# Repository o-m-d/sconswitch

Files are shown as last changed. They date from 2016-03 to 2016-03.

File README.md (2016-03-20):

# Serial Controlled Switch

## Device description
Device have 32 high voltage open collector outputs, controlled by commands
via RS-232 port. Outputs can be in active or passive state and can drive
relays, solenoids, LEDs, opto triacs etc.
Active state - output transistor open, passive state - output transistor
closed.

Device can be used in power control, lighting or any other suitable
applications.

Device connects to controlled system via 40-wire ribbon cable and to
controlling host via DE9 connector.

Device IS NOT realtime and may not used in time-sensitive applications,
e.g. CNC.

Device built on microcontroller ATmega8515-16 in TQFP44 package and
drivers ULN2803A in SOIC-18 package.

In firmware part used [KonstantinChizhov/Mcucpp library] (https://github.com/KonstantinChizhov/Mcucpp)
and [Peter Fleury UART library] (http://homepage.hispeed.ch/peterfleury/avr-software.html).
Firmware compiled by avr-gcc-4.8, pcb designed in KiCAD-4.0.1.

## Supported commands
<pre>
a N|a   - Active output number N (or all)
p N|a   - Passive output number N (or all)
t N D   - Toggle output N for D (1-255) seconds, press s for stop during 
          countdown
n NAME  - Output name, set to NAME or unset if empty given
s       - Show output status
h or ?  - Show this help
</pre>

Output status saved automatically to EEPROM with Active or Passive commands
and restored when power-up.
Commands are not case sensitive. Command line are not editable.

Outputs have numbers from 0 to 31. Toggle means temporary inversion of
output state.

[Demo video](https://youtu.be/6nN7ayRqDR0)

## Electrical characteristics
<pre>
Supply voltage: 9-15V
Supply current: 25mA at 10V
Max voltage on closed output: 50V
Max current via one open output: 500mA
Max total current via all open outputs: 4A (125mA per output and 2x2A per
two ground wires in ribbon cable)
</pre>

Characteristics depend on applied components.

## RS-232 mode
9600 8N1

## Design Recommendations
* Use short as possible ribbon cable.
* Use only 40-wire ribbon cable, not 80-wire UDMA cable.
* ULN2803 have built-in surge protection diodes for inductive load, but
better use discrete diodes, placed as close as possible to coil.

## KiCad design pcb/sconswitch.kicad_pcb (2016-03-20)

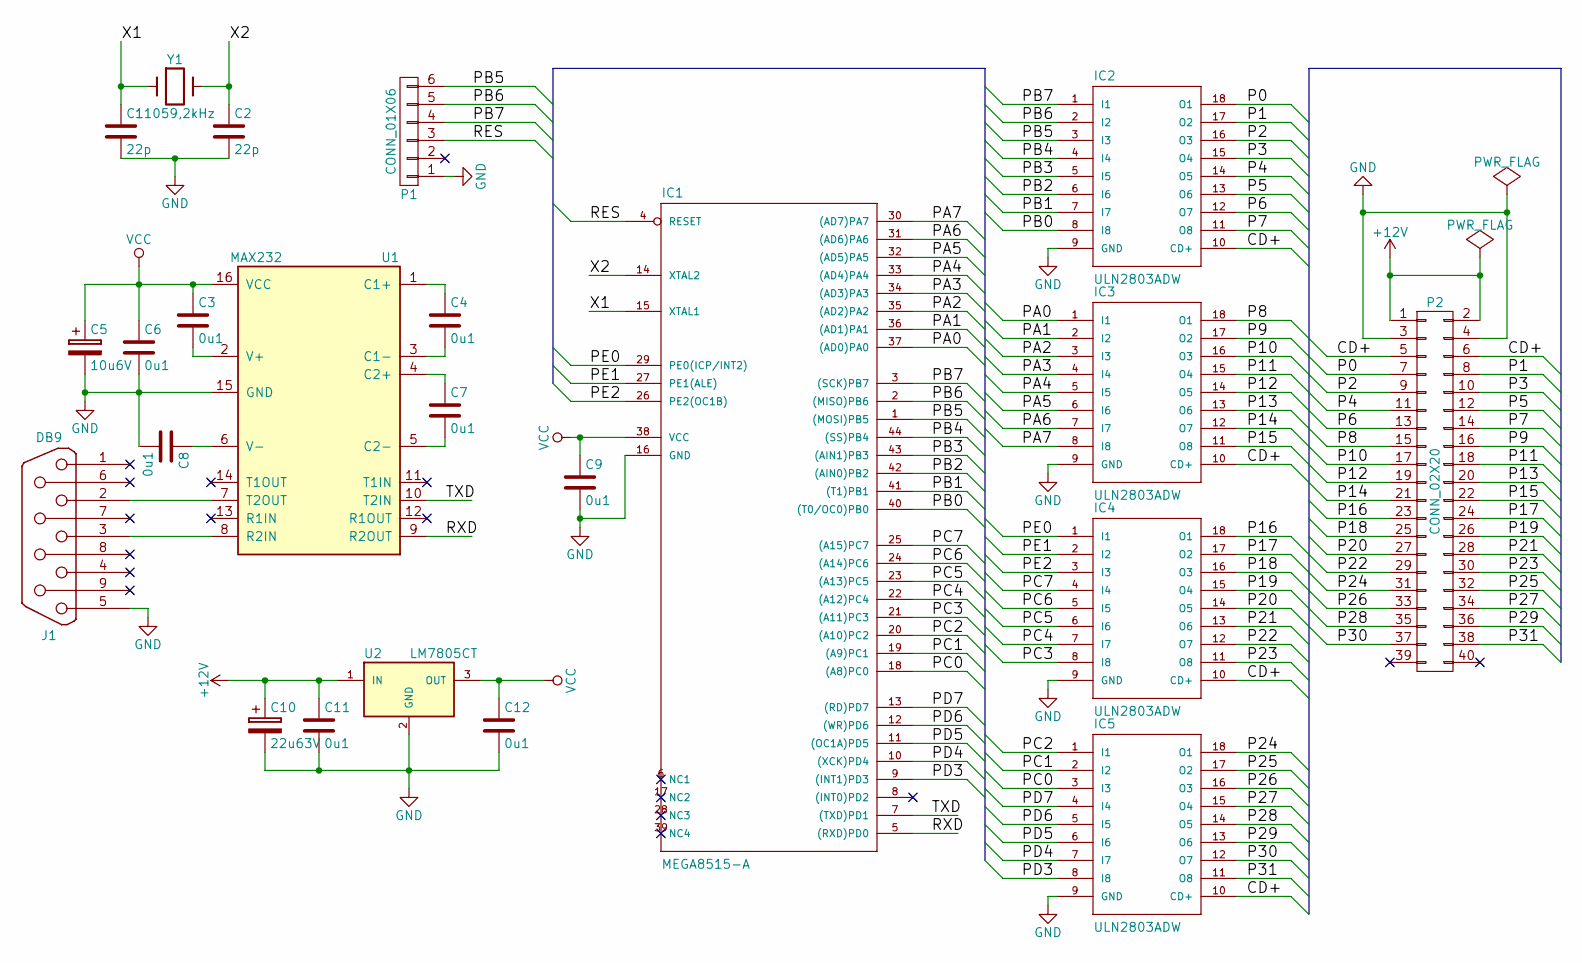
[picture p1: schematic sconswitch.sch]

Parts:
C1, C2: 22p; C_0603
C3, C4, C6, C7, C8, C9, C11, C12: 0u1; C_0603
C5: 10u6V; C_Radial_D5_L6_P2.5
C10: 22u63V; C_Radial_D10_L13_P5
IC1: MEGA8515-A; TQFP-44_10x10mm_Pitch0.8mm
IC2, IC3, IC4, IC5: ULN2803ADW; SOIC-18_7.5x11.6mm_Pitch1.27mm
J1: DB9; DB9FC
P1: CONN_01X06; Pin_Header_Straight_1x06
P2: CONN_02X20; Pin_Header_Straight_2x20
U1: MAX232; SO-16-N
U2: LM7805CT; TO-220_Horizontal_LargePads
Y1: 11059,2kHz; Crystal_HC49-U_Horizontal_Typ1

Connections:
+12V: C10.1, C11.1, P2.1, P2.2, U2.1 (IN)
/CD+: IC2.10 (CD+), IC3.10 (CD+), IC4.10 (CD+), IC5.10 (CD+), P2.5, P2.6
/P0: IC2.18 (O1), P2.7
/P1: IC2.17 (O2), P2.8
/P2: IC2.16 (O3), P2.9
/P3: IC2.15 (O4), P2.10
/P4: IC2.14 (O5), P2.11
/P5: IC2.13 (O6), P2.12
/P6: IC2.12 (O7), P2.13
/P7: IC2.11 (O8), P2.14
/P8: IC3.18 (O1), P2.15
/P9: IC3.17 (O2), P2.16
/P10: IC3.16 (O3), P2.17
/P11: IC3.15 (O4), P2.18
/P12: IC3.14 (O5), P2.19
/P13: IC3.13 (O6), P2.20
/P14: IC3.12 (O7), P2.21
/P15: IC3.11 (O8), P2.22
/P16: IC4.18 (O1), P2.23
/P17: IC4.17 (O2), P2.24
/P18: IC4.16 (O3), P2.25
/P19: IC4.15 (O4), P2.26
/P20: IC4.14 (O5), P2.27
/P21: IC4.13 (O6), P2.28
/P22: IC4.12 (O7), P2.29
/P23: IC4.11 (O8), P2.30
/P24: IC5.18 (O1), P2.31
/P25: IC5.17 (O2), P2.32
/P26: IC5.16 (O3), P2.33
/P27: IC5.15 (O4), P2.34
/P28: IC5.14 (O5), P2.35
/P29: IC5.13 (O6), P2.36
/P30: IC5.12 (O7), P2.37
/P31: IC5.11 (O8), P2.38
/PA0: IC1.37 ((AD0)PA0), IC3.1 (I1)
/PA1: IC1.36 ((AD1)PA1), IC3.2 (I2)
/PA2: IC1.35 ((AD2)PA2), IC3.3 (I3)
/PA3: IC1.34 ((AD3)PA3), IC3.4 (I4)
/PA4: IC1.33 ((AD4)PA4), IC3.5 (I5)
/PA5: IC1.32 ((AD5)PA5), IC3.6 (I6)
/PA6: IC1.31 ((AD6)PA6), IC3.7 (I7)
/PA7: IC1.30 ((AD7)PA7), IC3.8 (I8)
/PB0: IC1.40 ((T0/OC0)PB0), IC2.8 (I8)
/PB1: IC1.41 ((T1)PB1), IC2.7 (I7)
/PB2: IC1.42 ((AIN0)PB2), IC2.6 (I6)
/PB3: IC1.43 ((AIN1)PB3), IC2.5 (I5)
/PB4: IC1.44 ((SS)PB4), IC2.4 (I4)
/PB5: IC1.1 ((MOSI)PB5), IC2.3 (I3), P1.6
/PB6: IC1.2 ((MISO)PB6), IC2.2 (I2), P1.5
/PB7: IC1.3 ((SCK)PB7), IC2.1 (I1), P1.4
/PC0: IC1.18 ((A8)PC0), IC5.3 (I3)
/PC1: IC1.19 ((A9)PC1), IC5.2 (I2)
/PC2: IC1.20 ((A10)PC2), IC5.1 (I1)
/PC3: IC1.21 ((A11)PC3), IC4.8 (I8)
/PC4: IC1.22 ((A12)PC4), IC4.7 (I7)
/PC5: IC1.23 ((A13)PC5), IC4.6 (I6)
/PC6: IC1.24 ((A14)PC6), IC4.5 (I5)
/PC7: IC1.25 ((A15)PC7), IC4.4 (I4)
/PD3: IC1.9 ((INT1)PD3), IC5.8 (I8)
/PD4: IC1.10 ((XCK)PD4), IC5.7 (I7)
/PD5: IC1.11 ((OC1A)PD5), IC5.6 (I6)
/PD6: IC1.12 ((WR)PD6), IC5.5 (I5)
/PD7: IC1.13 ((RD)PD7), IC5.4 (I4)
/PE0: IC1.29 (PE0(ICP/INT2)), IC4.1 (I1)
/PE1: IC1.27 (PE1(ALE)), IC4.2 (I2)
/PE2: IC1.26 (PE2(OC1B)), IC4.3 (I3)
/RES: IC1.4 (RESET), P1.3
/RXD: IC1.5 ((RXD)PD0), U1.9 (R2OUT)
/TXD: IC1.7 ((TXD)PD1), U1.10 (T2IN)
/X1: C1.1, IC1.15 (XTAL1), Y1.1
/X2: C2.1, IC1.14 (XTAL2), Y1.2
GND: C1.2, C2.2, C5.2, C6.2, C8.2, C9.2, C10.2, C11.2, C12.2, IC1.16 (GND), IC2.9 (GND), IC3.9 (GND), IC4.9 (GND), IC5.9 (GND), J1.5, P1.1, P2.3, P2.4, U1.15 (GND), U2.2 (GND)
unnamed: C3.2, U1.2 (V+)
unnamed: C4.1, U1.1 (C1+)
unnamed: C4.2, U1.3 (C1-)
unnamed: C7.1, U1.4 (C2+)
unnamed: C7.2, U1.5 (C2-)
unnamed: C8.1, U1.6 (V-)
unnamed: J1.2, U1.7 (T2OUT)
unnamed: J1.3, U1.8 (R2IN)
VCC: C3.1, C5.1, C6.1, C9.1, C12.1, IC1.38 (VCC), U1.16 (VCC), U2.3 (OUT)

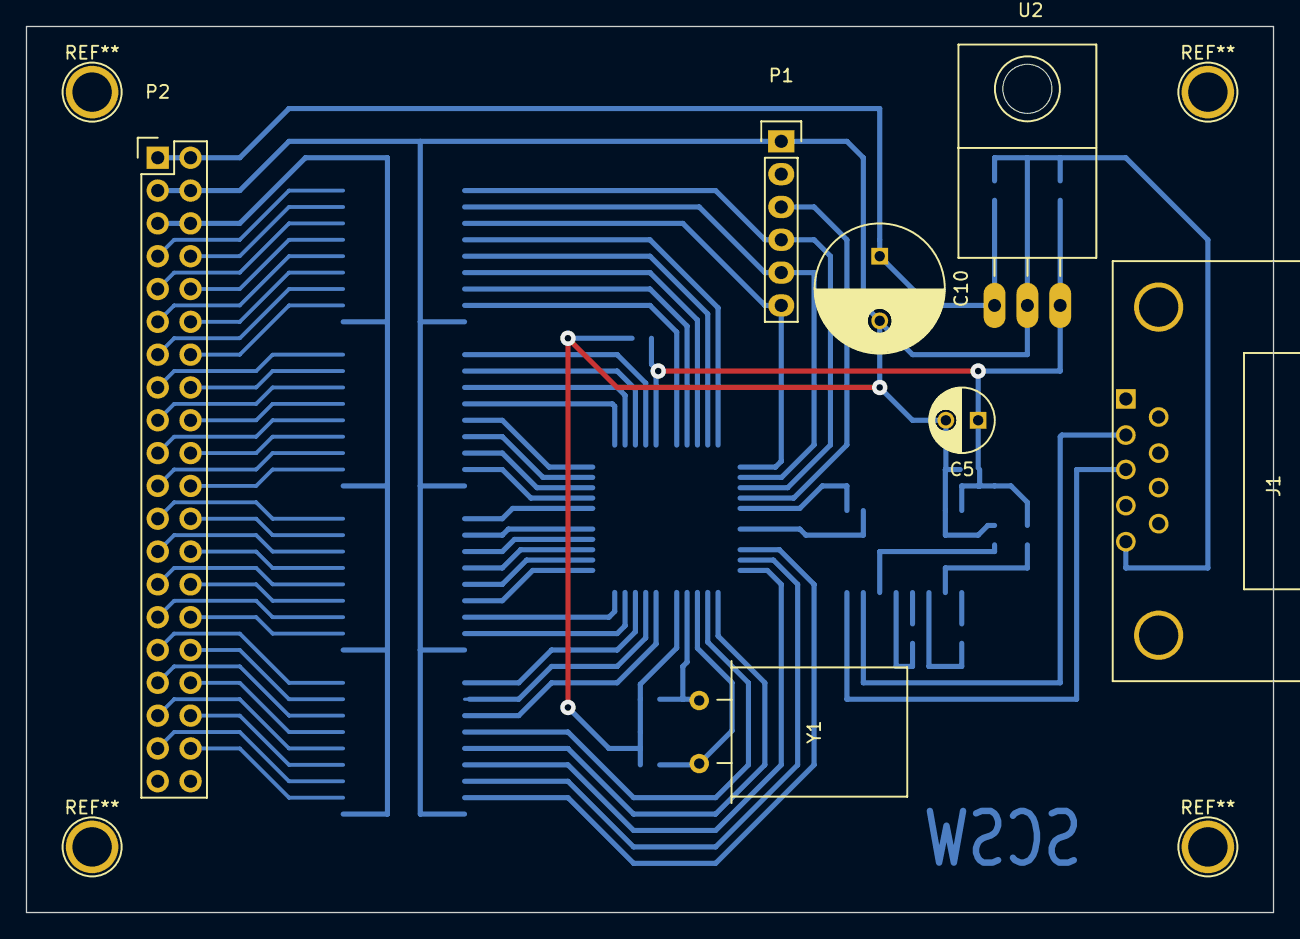
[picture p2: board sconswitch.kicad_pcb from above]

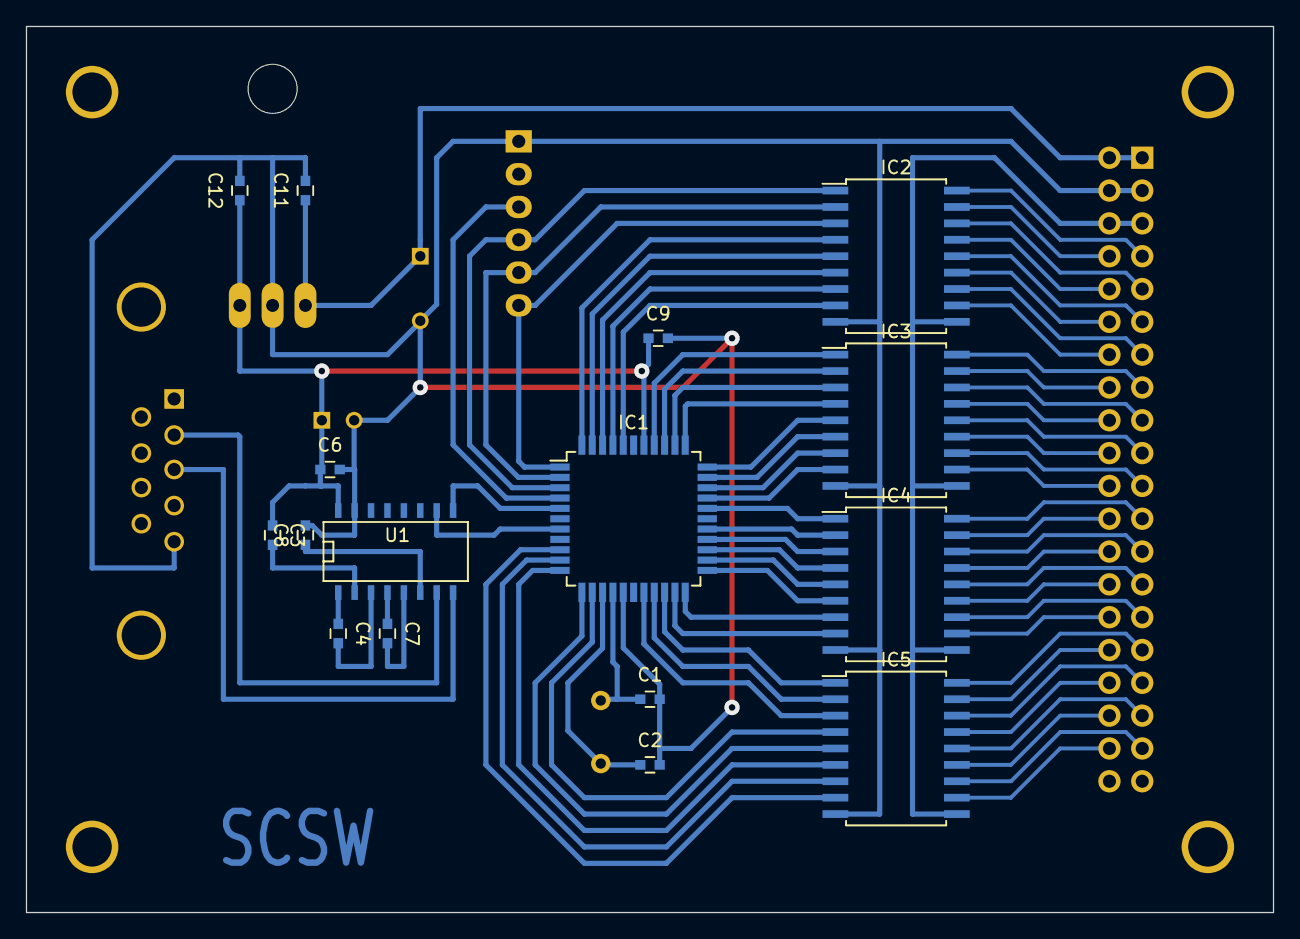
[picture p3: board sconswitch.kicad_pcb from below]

Board: 2 copper layers, 96.5 x 68.6 mm, 23 parts (16 on the bottom side), 81 nets.

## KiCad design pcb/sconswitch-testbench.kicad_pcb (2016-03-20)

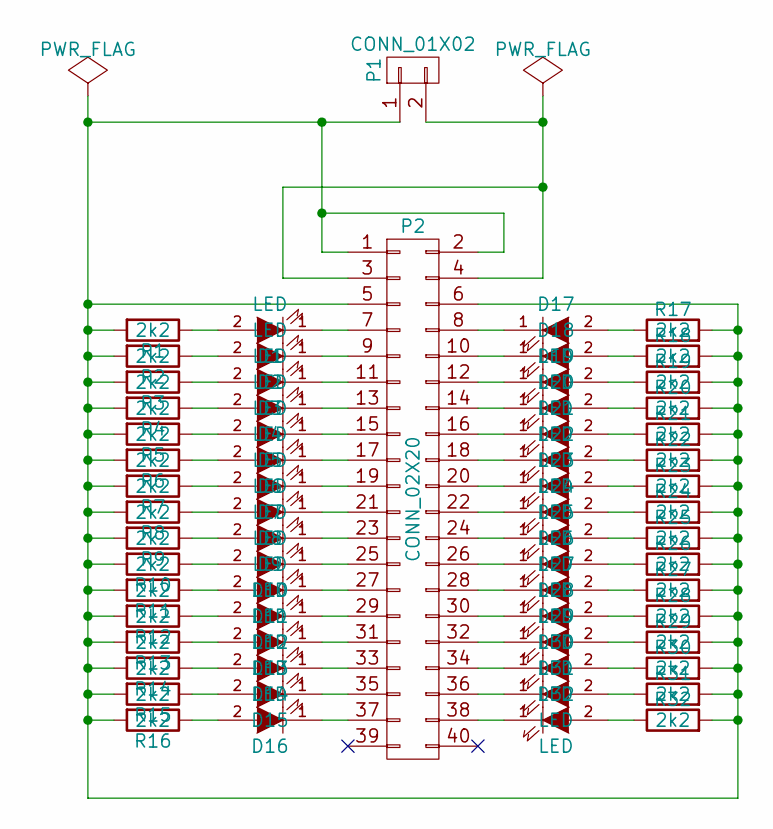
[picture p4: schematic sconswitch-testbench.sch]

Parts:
D1, D2, D3, D4, D5, D6, D7, D8, D9, D10, D11, D12, D13, D14, D15, D16, D17, D18, D19, D20, D21, D22, D23, D24, D25, D26, D27, D28, D29, D30, D31, D32: LED; LED_0805
P1: CONN_01X02; TerminalBlock_Pheonix_MKDS1.5-2pol
P2: CONN_02X20; Pin_Header_Straight_2x20
R1, R2, R3, R4, R5, R6, R7, R8, R9, R10, R11, R12, R13, R14, R15, R16, R17, R18, R19, R20, R21, R22, R23, R24, R25, R26, R27, R28, R29, R30, R31, R32: 2k2; R_0805

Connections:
unnamed: D1.1 (K), P2.7
unnamed: D1.2 (A), R1.1
unnamed: D2.1 (K), P2.9
unnamed: D2.2 (A), R2.1
unnamed: D3.1 (K), P2.11
unnamed: D3.2 (A), R3.1
unnamed: D4.1 (K), P2.13
unnamed: D4.2 (A), R4.1
unnamed: D5.1 (K), P2.15
unnamed: D5.2 (A), R5.1
unnamed: D6.1 (K), P2.17
unnamed: D6.2 (A), R6.1
unnamed: D7.1 (K), P2.19
unnamed: D7.2 (A), R7.1
unnamed: D8.1 (K), P2.21
unnamed: D8.2 (A), R8.1
unnamed: D9.1 (K), P2.23
unnamed: D9.2 (A), R9.1
unnamed: D10.1 (K), P2.25
unnamed: D10.2 (A), R10.1
unnamed: D11.1 (K), P2.27
unnamed: D11.2 (A), R11.1
unnamed: D12.1 (K), P2.29
unnamed: D12.2 (A), R12.1
unnamed: D13.1 (K), P2.31
unnamed: D13.2 (A), R13.1
unnamed: D14.1 (K), P2.33
unnamed: D14.2 (A), R14.1
unnamed: D15.1 (K), P2.35
unnamed: D15.2 (A), R15.1
unnamed: D16.1 (K), P2.37
unnamed: D16.2 (A), R16.1
unnamed: D17.1 (K), P2.8
unnamed: D17.2 (A), R17.1
unnamed: D18.1 (K), P2.10
unnamed: D18.2 (A), R18.1
unnamed: D19.1 (K), P2.12
unnamed: D19.2 (A), R19.1
unnamed: D20.1 (K), P2.14
unnamed: D20.2 (A), R20.1
unnamed: D21.1 (K), P2.16
unnamed: D21.2 (A), R21.1
unnamed: D22.1 (K), P2.18
unnamed: D22.2 (A), R22.1
unnamed: D23.1 (K), P2.20
unnamed: D23.2 (A), R23.1
unnamed: D24.1 (K), P2.22
unnamed: D24.2 (A), R24.1
unnamed: D25.1 (K), P2.24
unnamed: D25.2 (A), R25.1
unnamed: D26.1 (K), P2.26
unnamed: D26.2 (A), R26.1
unnamed: D27.1 (K), P2.28
unnamed: D27.2 (A), R27.1
unnamed: D28.1 (K), P2.30
unnamed: D28.2 (A), R28.1
unnamed: D29.1 (K), P2.32
unnamed: D29.2 (A), R29.1
unnamed: D30.1 (K), P2.34
unnamed: D30.2 (A), R30.1
unnamed: D31.1 (K), P2.36
unnamed: D31.2 (A), R31.1
unnamed: D32.1 (K), P2.38
unnamed: D32.2 (A), R32.1
unnamed: P1.1, P2.1, P2.2, P2.5, P2.6, R1.2, R2.2, R3.2, R4.2, R5.2, R6.2, R7.2, R8.2, R9.2, R10.2, R11.2, R12.2, R13.2, R14.2, R15.2, R16.2, R17.2, R18.2, R19.2, R20.2, R21.2, R22.2, R23.2, R24.2, R25.2, R26.2, R27.2, R28.2, R29.2, R30.2, R31.2, R32.2
unnamed: P1.2, P2.3, P2.4

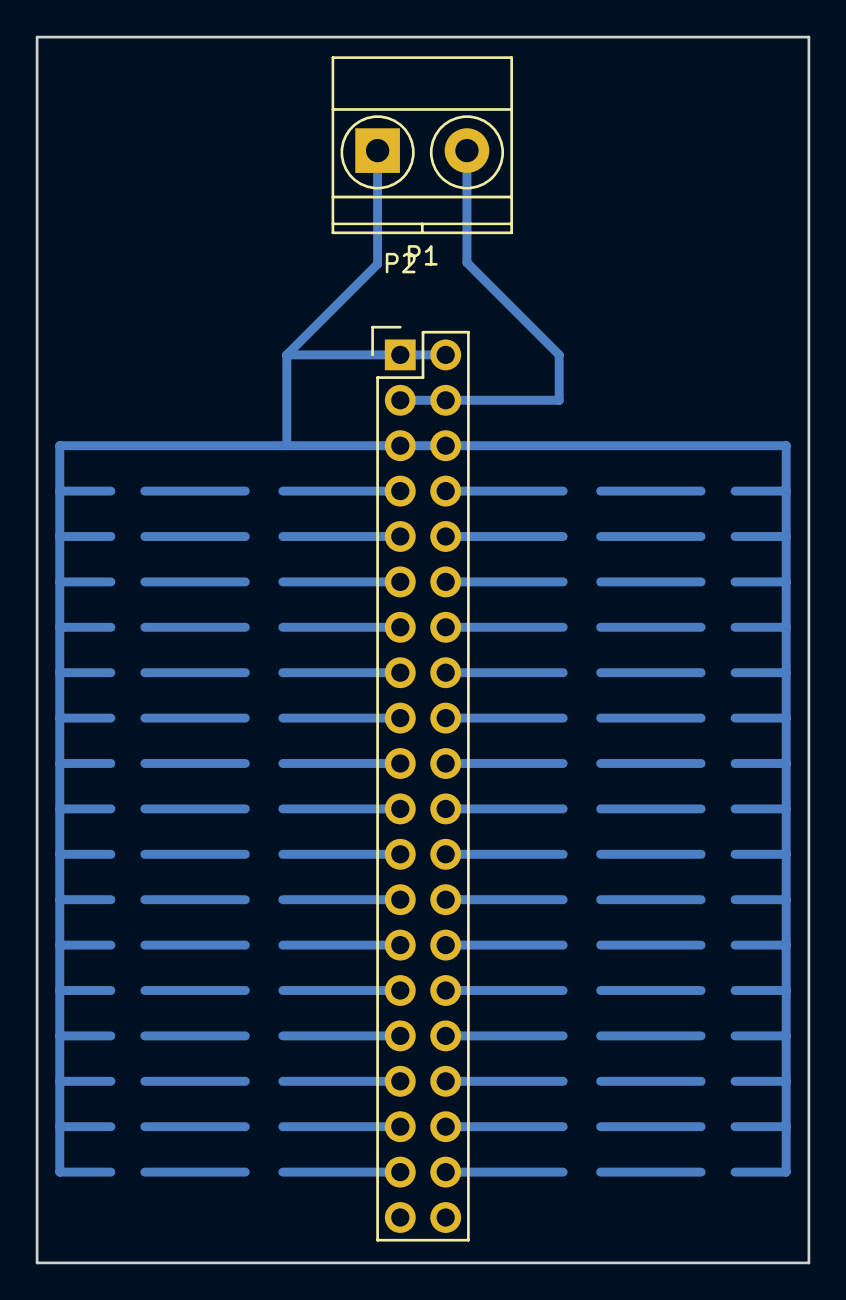
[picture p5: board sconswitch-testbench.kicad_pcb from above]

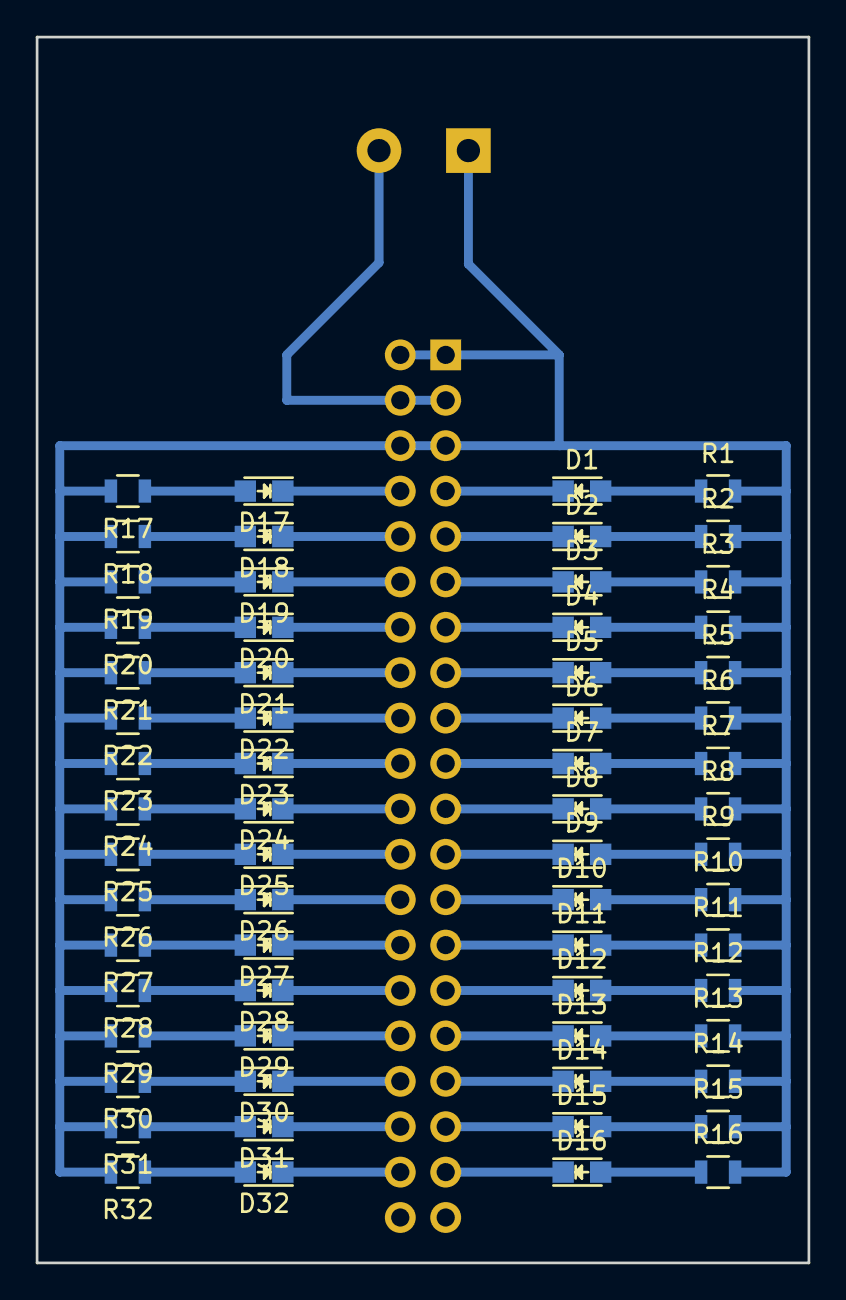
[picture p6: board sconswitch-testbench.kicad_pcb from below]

Board: 2 copper layers, 43.2 x 68.6 mm, 66 parts (64 on the bottom side), 66 nets.

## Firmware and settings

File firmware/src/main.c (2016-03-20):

/*************************************************************************
 * Title:           Serial Controlled Switch
 * Author:          Olexandr Davydenko
 * Description:     32 output channels, controlled by commands via serial port.
*************************************************************************/

#include <ctype.h>
#include <inttypes.h>
#include <stdlib.h>
#include <stdio.h>
#include <string.h>
#include <avr/eeprom.h>
#include <avr/interrupt.h>
#include <avr/io.h>
#include <avr/pgmspace.h>
#include <avr/wdt.h>
#include <util/delay.h>

#include "main.h"

#include "uart.h"

// MCUCPP
#include "iopins.h"
#include "pinlist.h"

using namespace Mcucpp::IO;

typedef PinList <Pb7, Pb6, Pb5, Pb4, Pb3, Pb2, Pb1, Pb0, Pa0, Pa1, Pa2, Pa3, Pa4, Pa5, Pa6, Pa7, Pe0, Pe1, Pe2, Pc7, Pc6, Pc5, Pc4, Pc3, Pc2, Pc1, Pc0, Pd7, Pd6, Pd5, Pd4, Pd3> mainport;

const int8_t mainport_width = mainport::PinListProperties::Length - 1;
uint32_t mainport_data;

void cleanbuf(char *arr_start, char *arr_end);
void actionchan(uint8_t chan, char action);
void togglechan(uint8_t chan, uint16_t delay);
void parse_cmndline(char *command_part[], char *buffer);
void showportstatus();

int main(void)
{
    uint16_t read_char; //because UART_* errors are 16 bit
    uint16_t delay;
    char buffer[UART_CMND_SIZE], *command_part[MAX_CMDARG_COUNT], command;
    uint8_t charcount = 0, chan;

    mainport::SetConfiguration(mainport::Out);

    // check if this fist work with empty EEPROM
    if (eeprom_read_byte(EE_FLAG_NEW) == 0xff)
    {
        eeprom_write_byte(EE_FLAG_NEW, 0);
        eeprom_write_dword(EE_BASE_PORT, 0);
    }
    mainport_data = eeprom_read_dword(EE_BASE_PORT);
    mainport::Write(mainport_data);

    wdt_reset();
    wdt_enable(WDTO_2S);

    uart_init(UART_BAUD_SELECT(UART_BAUD_RATE,F_CPU));
    sei();
    cleanbuf(buffer, buffer+UART_CMND_SIZE);
    U_HELP;
    U_PROMPT;

    for (;;)
    {
        wdt_reset();
        // get char and verify UART status
        read_char = uart_getc();
        if (read_char == UART_NO_DATA)
        {
        }
        else
        {
            if (read_char == UART_FRAME_ERROR)
            {
                U_F;
            }
            if (read_char == UART_OVERRUN_ERROR)
            {
                U_OR;
            }
            if (read_char == UART_BUFFER_OVERFLOW)
            {
                U_OF;
            }

            // Enter pressed
            if ((read_char == 0x0a) || (read_char == 0x0d))
            {
                // parse commandline
                parse_cmndline(command_part, buffer);

                // first argument
                if (command_part[0])
                {
                    command = tolower(*command_part[0]);
                    switch (command)
                    {
                        case 'h':
                        case '?':
                            U_HELP;
                            break;

                        case 's':
                            showportstatus();
                            break;

                        case 'a':
                        case 'p':
                            chan = atoi(command_part[1]);
                            if ((LOWCHAN > chan) || (chan > mainport_width) || (!isdigit(*command_part[1]) && (tolower(*command_part[1]) != 'a')))
                            {
                                U_ERR;
                                goto ENDPARSE;
                            }
                            if (tolower(*command_part[1]) == 'a')
                            {
                                if (command == 'p')
                                {
                                    mainport_data = 0;
                                }
                                if (command == 'a')
                                {
                                    mainport_data = 0xffffffffUL;
                                }
                                mainport::Write(mainport_data);
                                goto end_of_switch;
                            }
                            actionchan(chan, command);

                            end_of_switch:
                            eeprom_write_dword(EE_BASE_PORT, mainport_data);
                            break;

                        case 't':
                            // find second argument - channel num
                            chan = atoi(command_part[1]);
                            if ((LOWCHAN > chan) || (chan > mainport_width) || !isdigit(*command_part[1]))
                            {
                                U_ERR;
                                goto ENDPARSE;
                            }
                            // find third argument - delay
                            delay = atoi(command_part[2]);
                            if ((LOWDLY > delay) || (delay > HIGHDLY))
                            {
                                U_ERR;
                                goto ENDPARSE;
                            }
                            togglechan(chan, delay);
                            break;

                        case 'n':
                            // find second argument - channel num
                            chan = atoi(command_part[1]);
                            if ((LOWCHAN > chan) || (chan > mainport_width) || !isdigit(*command_part[1]))
                            {
                                U_ERR;
                                goto ENDPARSE;
                            }
                            // find third argument - channel name
                            if ((strlen(command_part[2]) > CHAN_NAME_SIZE))
                            {
                                U_ERR;
                                goto ENDPARSE;
                            }
                            else if (!command_part[2])
                            {
                                // erase channel name
                                int8_t name_char = CHAN_NAME_SIZE;
                                while (name_char > 0)
                                {
                                    name_char--;
                                    eeprom_write_byte((uint8_t*)(EE_BASE_NAMES + (chan * CHAN_NAME_SIZE) + name_char), 0xff);
                                }

                                goto ENDPARSE;
                            }
                            else
                            {
                                // save channel name
                                eeprom_write_block((const void*)command_part[2],  (void*)(EE_BASE_NAMES + (chan * CHAN_NAME_SIZE)), CHAN_NAME_SIZE);
                                goto ENDPARSE;
                            }
                            break;

                        default:
                            U_ERR;
                            U_HELP;
                            goto ENDPARSE;
                    }
                }

ENDPARSE:
                charcount = 0;
                cleanbuf(buffer, buffer+UART_CMND_SIZE);
                U_PROMPT;
            }
            else
            {
                // Accumulate chars of command line
                if (charcount < UART_CMND_SIZE - 1)
                {
                    uart_putc((unsigned char)read_char);
                    buffer[charcount] = read_char;
                    charcount++;
                }
                // Detect command line oversize
                else
                {
                    charcount = 0;
                    cleanbuf(buffer, buffer+UART_CMND_SIZE);
                    U_CMNDLONG;
                    U_PROMPT;
                }
            }
        }
    }
}

void cleanbuf(char *arr_start, char *arr_end)
{
    while (arr_start < arr_end)
    {
        *(arr_start++) = 0;
    }
}

void actionchan(uint8_t chan, char action)
{
    uint32_t ui32Chanstatus;
    ui32Chanstatus = mainport_data;

    if (action == 'p')
    {
        mainport_data = (ui32Chanstatus &= ~(1UL << chan));
        mainport::Write(mainport_data);
    }
    else if (action == 'a')
    {
        mainport_data = (ui32Chanstatus |= (1UL << chan));
        mainport::Write(mainport_data);
    }
    else
    {
        U_ERR;
    }
}

void showportstatus()
{
    int8_t i;
    char cPortstatus[UART_CMND_SIZE], cChanName[CHAN_NAME_SIZE + 1];

    for (i = mainport_width; i >= 0; i--)
    {
        uart_puts_P("\r\nOutput ");
        uart_puts(itoa(i, cPortstatus, 10));
        uart_puts_P("\t");

        eeprom_read_block((void *) cChanName, (const void *) (EE_BASE_NAMES + (i * CHAN_NAME_SIZE)), CHAN_NAME_SIZE);
        if (cChanName[0] != 0xff)
        {
            cChanName[CHAN_NAME_SIZE] = 0;
            uart_puts(cChanName);
            if (strlen(cChanName) < CHAN_NAME_SIZE)
            {
                uart_puts_P("\t");
            }
        }
        else
        {
            uart_puts_P("\t");
        }

        if (mainport_data & (1UL << i))
        {
            uart_puts_P("\tActive");
        }
        else
        {
            uart_puts_P("\tPassive");
        }
    }
}

void togglechan(uint8_t chan, uint16_t delay)
{
    uint32_t ui32tmp = mainport_data;
    uint16_t read_char;
    char cPortstatus[UART_CMND_SIZE];

    if (mainport_data & (1UL << chan))
    {
        mainport::Write(ui32tmp &= ~(1UL << chan));
    }
    else
    {
        mainport::Write(ui32tmp |= (1UL << chan));
    }

    uart_puts_P("\r\nStart toggle. Press s for stop. Remain ");

    while (delay > 0)
    {
        uart_puts(itoa(delay, cPortstatus, 10));
        uart_puts_P("\e[K"); //erase to end of line
        wdt_reset();
        _delay_ms(250);
        wdt_reset();
        _delay_ms(250);
        wdt_reset();
        _delay_ms(250);
        wdt_reset();
        _delay_ms(250);
        delay--;

        // return cursor to position for display numbers
        if (delay >= 99)
        {
            uart_puts_P("\b\b\b");
        }
        else if (delay >= 9)
        {
            uart_puts_P("\b\b");
        }
        else
        {
            uart_puts_P("\b");
        }

        read_char = uart_getc();
        if (read_char == UART_NO_DATA)
        {
        }
        else
        {
            if ((read_char == 0x53) || (read_char == 0x73))
            {
                break;
            }
        }
    }
    if (delay == 0)
    {
        uart_puts_P("\r\nDone");
    }
    else
    {
        uart_puts_P("\r\nStopped");
    }
    mainport::Write(mainport_data);
}

void parse_cmndline(char *command_part[], char *buffer)
{
    int8_t command_part_count = 0;
    command_part[command_part_count] = strtok(buffer, " ");
    while (command_part_count < MAX_CMDARG_COUNT)
    {
        command_part_count++;
        command_part[command_part_count] = strtok(NULL, " ");
    }
}

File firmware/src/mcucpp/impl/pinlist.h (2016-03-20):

//*****************************************************************************
//
// Author		: Konstantin Chizhov
// Date			: 2013
// All rights reserved.

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
#include <static_if.h>
#include <select_size.h>

namespace Mcucpp
{
namespace IO
{
	using namespace Loki;
	using namespace Loki::TL;

	namespace IoPrivate
	{

////////////////////////////////////////////////////////////////////////////////
// class template CheckSameConfig
// Checks if all ports has the same configuration enum
// PlaceHolderType matchs any type in TList
////////////////////////////////////////////////////////////////////////////////

		template <class TList, class CurrentConfig = typename TList::Head::Configuration>
		struct CheckSameConfigImp;

		template<class TList, class CurrentConfig, class NextConfig>
		struct CheckSameConfigHelper
		{
			static const bool value = false;
		};

		template<class Head, class Tail, class CurrentConfig>
		struct CheckSameConfigHelper<Typelist<Head, Tail>, CurrentConfig, CurrentConfig>
		{
			static const bool value = CheckSameConfigImp<Tail, CurrentConfig>::value;
		};

		template <class CurrentConfig> struct CheckSameConfigImp<NullType, CurrentConfig>
		{
			static const bool value = true;
		};

		template <class Head, class Tail, class CurrentConfig>
		struct CheckSameConfigImp<Typelist<Head, Tail>, CurrentConfig>
		{
			static const bool value = CheckSameConfigHelper<Typelist<Head, Tail>, CurrentConfig, typename Head::Configuration>::value;
		};

		template <class TList>
		struct CheckSameConfig
		{
			static const bool value = CheckSameConfigImp<TList, typename TList::Head::Configuration>::value;
		};

		template <>
		struct CheckSameConfig<NullType>
		{
				static const bool value = true;
		};


////////////////////////////////////////////////////////////////////////////////
		template <class TList, class T, class ConfigT>
		struct ErisePortsHelper;

		template <class TList, class T>
		struct ErasePortsWithConfig
		{
			typedef typename ErisePortsHelper<TList, T, typename TList::Head::Configuration>::Result Result;
		};

		template < class T>
		struct ErasePortsWithConfig<NullType, T>
		{
			typedef NullType Result;
		};

		template <class T, class ConfigT>
		struct ErisePortsHelper<NullType, T, ConfigT>
		{
			typedef NullType Result;
		};

		template <class Head, class Tail, class T>
		struct ErisePortsHelper<Typelist<Head, Tail>, T, T>
		{
			// Go all the way down the list removing the type
			typedef typename ErasePortsWithConfig<Tail, T>::Result Result;
		};

		template <class Head, class Tail, class T, class ConfigT>
		struct ErisePortsHelper<Typelist<Head, Tail>, T, ConfigT>
		{
			// Go all the way down the list removing the type
			typedef Typelist<Head,
					typename ErasePortsWithConfig<Tail, T>::Result>
				Result;
		};

////////////////////////////////////////////////////////////////////////////////

		template<unsigned BitsToShift>
		struct ShiftLeft
		{
			template<class T>
			static T Shift(T value)
			{
				return value << BitsToShift;
			}
		};

		template<unsigned BitsToShift>
		struct ShiftRight
		{
			template<class T>
			static T Shift(T value)
			{
				return value >> BitsToShift;
			}
		};

		enum MapDirection{ValueToPort = 1 , PortToValue = 0};

		template<unsigned First, unsigned Second, MapDirection mapDirection>
		class Shifter
		{
			typedef ShiftRight<First - Second> RightShifter1;
			typedef ShiftRight<Second - First> RightShifter2;

			typedef ShiftLeft<First - Second> LeftShifter1;
			typedef ShiftLeft<Second - First> LeftShifter2;

			static const bool ShiftDirection = First > Second;
			typedef typename StaticIf<ShiftDirection, LeftShifter1, RightShifter2>::Result FirstShifter;
			typedef typename StaticIf<ShiftDirection, RightShifter1, LeftShifter2>::Result SecondShifter;

			typedef typename StaticIf<mapDirection, FirstShifter, SecondShifter>::Result ActualShifter;
		public:
			template<class T>
			static T Shift(T value)
			{
				return ActualShifter::Shift(value);
			}
		};

////////////////////////////////////////////////////////////////////////////////
		template<class PINS> struct GetLastBitPosition;

		template<>
		struct GetLastBitPosition<NullType>
		{
			static const unsigned value = 0;
		};

		template<class Head>
		struct GetLastBitPosition<Typelist<Head, NullType> >
		{
			static const unsigned value = Head::Position;
		};

		template<class Head, class Tail>
		struct GetLastBitPosition<Typelist<Head, Tail> >
		{
			static const unsigned value = GetLastBitPosition<Tail>::value;
		};

////////////////////////////////////////////////////////////////////////////////
// Holds a Pin class and its bit position in value to read/write
////////////////////////////////////////////////////////////////////////////////

		template<class TPIN, uint8_t POSITION>
		struct PinPositionHolder
		{
			typedef TPIN Pin;
			static const unsigned Position = POSITION;
		};
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

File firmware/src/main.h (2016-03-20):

/*************************************************************************
 * Title:           Serial Controlled Switch
 * Author:          Olexandr Davydenko
 * Description:     32 output channels, controlled by commands via serial port.
*************************************************************************/

# ifndef _MAIN_H
# define _MAIN_H

#define LOWCHAN                     0

#define LOWDLY                      1
#define HIGHDLY                     255

#define EE_BASE_PORT                (uint32_t *)(0x10)
#define EE_FLAG_NEW                 (uint8_t *)(0x08)
#define EE_BASE_NAMES               0x20
#define CHAN_NAME_SIZE              8
#define MAX_CMDARG_COUNT            5    //don't forget proper init array elements

#define UART_BAUD_RATE              9600
#define UART_CMND_SIZE              32

//UART messages
#define U_HELP uart_puts_P("\r\n\r\n\r\n\t\t-= SConSwitch =-\r\nAvailable commands:\r\n\ta N|a\t- Active output number N (or all)\r\n\tp N|a\t- Passive output number N (or all)\r\n\tt N D\t- Toggle output N for D (1-255) seconds, press s for stop during countdown\r\n\tn NAME\t- Channel name, set to NAME or unset if empty\r\n\ts\t- Show output status\r\n\th or ?\t- Show this help\r\n\r\nOutput status saved automatically to EEPROM with Active or Passive commands and restored when power-up.\r\nCommands are not case sensitive. Command line are not editable.\r\n\r\n");
#define U_PROMPT uart_puts_P("\r\nSConSwitch > ");
#define U_F uart_puts_P("\r\nUART Frame Error.\r\n");
#define U_OR uart_puts_P("\r\nUART Overrun Error.\r\n");
#define U_OF uart_puts_P("\r\nBuffer overflow error.\r\n");
#define U_CMNDLONG uart_puts_P("\r\nCommand too long.\r\n");
#define U_ERR uart_puts_P("\r\nCommand error.\r\n");

# endif // _MAIN_H
